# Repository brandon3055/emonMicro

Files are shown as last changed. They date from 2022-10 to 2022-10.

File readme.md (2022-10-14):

# EmonMicro

This is a small self-contained energy monitoring device designed to work with [Open Energy Monitor](https://openenergymonitor.org/)

I recently installed an open energy monitor EmonTx v4 so that I could monitor the power usage of that various circuits in my house. 
but I found myself wanting more information. The tx v4 can for example tell me how much power is being used by the bedroom circuit,
but it can't tell me how much power is going to each room or appliance. This project was started as a solution.

## Disclaimer!
I am not a qualified electrical engineer! I am just a hobbyist who occasionally likes to design and build things.
I am releasing this design so that others may learn from it and possibly improve on it.
If you choose to build this device you do so at your own risk! If it happens to burst into flames, or you
electrocute yourself because you're not qualified to work on mains-powered devices I can not be held responsible.

### The design
The idea behind this project was to build an energy monitor in a form factor similar to a standard power strip.
The board supports up to four separate channels, but I found the most I personally need was three and in most cases i only need one.
Unused channels can simply be left unpopulated.

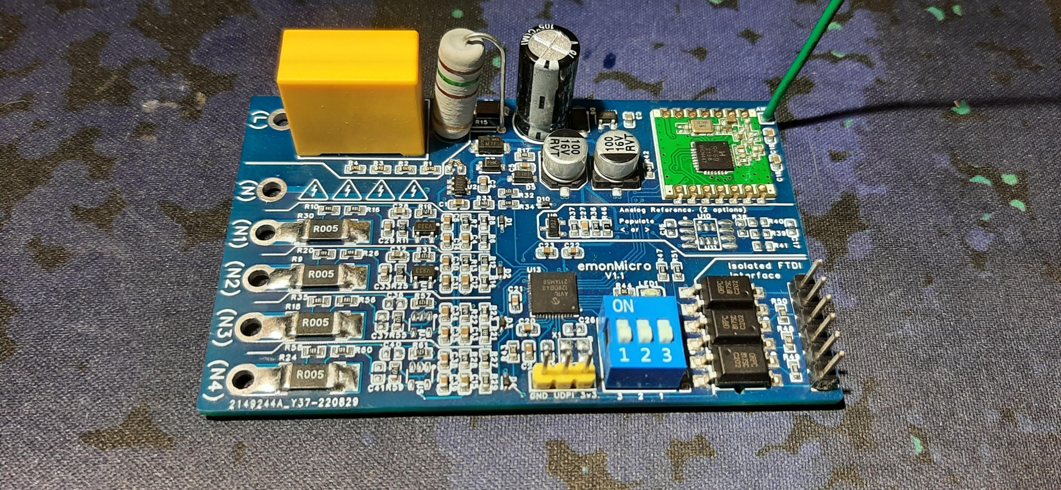
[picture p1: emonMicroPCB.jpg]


For the sockets I used [PW1-0W](https://www.wagneronline.com.au/ac-power-installation/power-240vac/power-lighting/pw1-0w-35241/973869/pd/) panel mount sockets.  
As well as a couple sockets I pulled out of an old UPS.

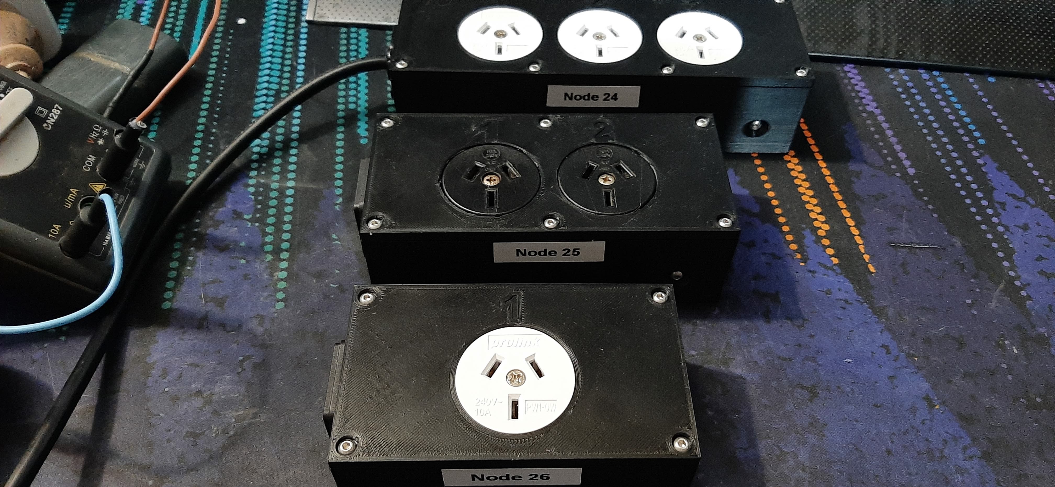
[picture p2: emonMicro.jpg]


For the power input I decided to go with 10A fused IEC ports. I chose these because both the ports and the plugs are rated at 10 amps
and you can get them with built-in fuses, so they seemed like a convenient solution. 
**Turns out this was a mistake...** I later discovered that although the plugs are rated for 10 amps
the vast majority of IEC cables use 0.75mm2 conductors which are only rated for around 7 amps.
So to work around this I have to forgo the fuse and hard-wire suitable cords for use cases that require more than 7 amp capacity.

### Safety and Isolation
Unlike all other OEM devices this design has no isolation between mains and the low voltage electronics.
By eliminating the bulky isolation components and switching to a transformerless power supply I was able to make
the board very compact and reduce component cost. The downside is this means the low voltage electronics are referenced to mains so the entire board
must be fully enclosed in a proper safe enclosure when the device is powered.
This is fine in normal operation but the device still needs to be connected to a computer while powered in order to be calibrated.
The solution I came up with was to add an optically isolated FTDI port that can be safely connected to an FTDI adapter. 

This also means you can't use an external antenna but with a plastic enclosure and internal antenna glued around the perimeter of the box 
seems to provide pretty good range.  

### The power supply and use with 110v power
The only thing stopping this from working with 110v is the value of the capacitor in the transformerless power supply.
I ran some basic simulations to get a rough idea of the value I needed but the monitor does not use a consistent amount of current.
Instead, mostly just sips power until it needs to transmit at which point the TX module pules up to 45ma in short bursts.
Through a bit of trial and error I found that a 680nf input cap with 1000uf buffer cap charged to 9v can more than 
handle the power demands of normal operation. 
on a 110v supply you could theoretically just double value of the input capacitor. Though that would require some testing to be sure.  

### Future plans? 
As of writing this I don't have any immediate plans to continue working on this project.
But its possible I may re visit this project in the future.

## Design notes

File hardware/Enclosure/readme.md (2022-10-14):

# Caution!

If you choose to build these monitors I recommend using a properly rated off the shelf enclosure. 
Failure of the enclosure could result in electrocution. 

If you do choose to print these enclosures I recommend a minimum of 4 perimeters, 5 top/bottom layers and 40% cubic infill.
And please...
#### Do not use PLA!
Seriously. PLA is great for toys and trinkets but with a glass transition temp of 60C you may as well be using candle wax.
I used ABS for my enclosures but PETG *may* also be acceptable.

Just keep in mind if the enclosure fails someone could be electrocuted. So be sure you know what you are doing.

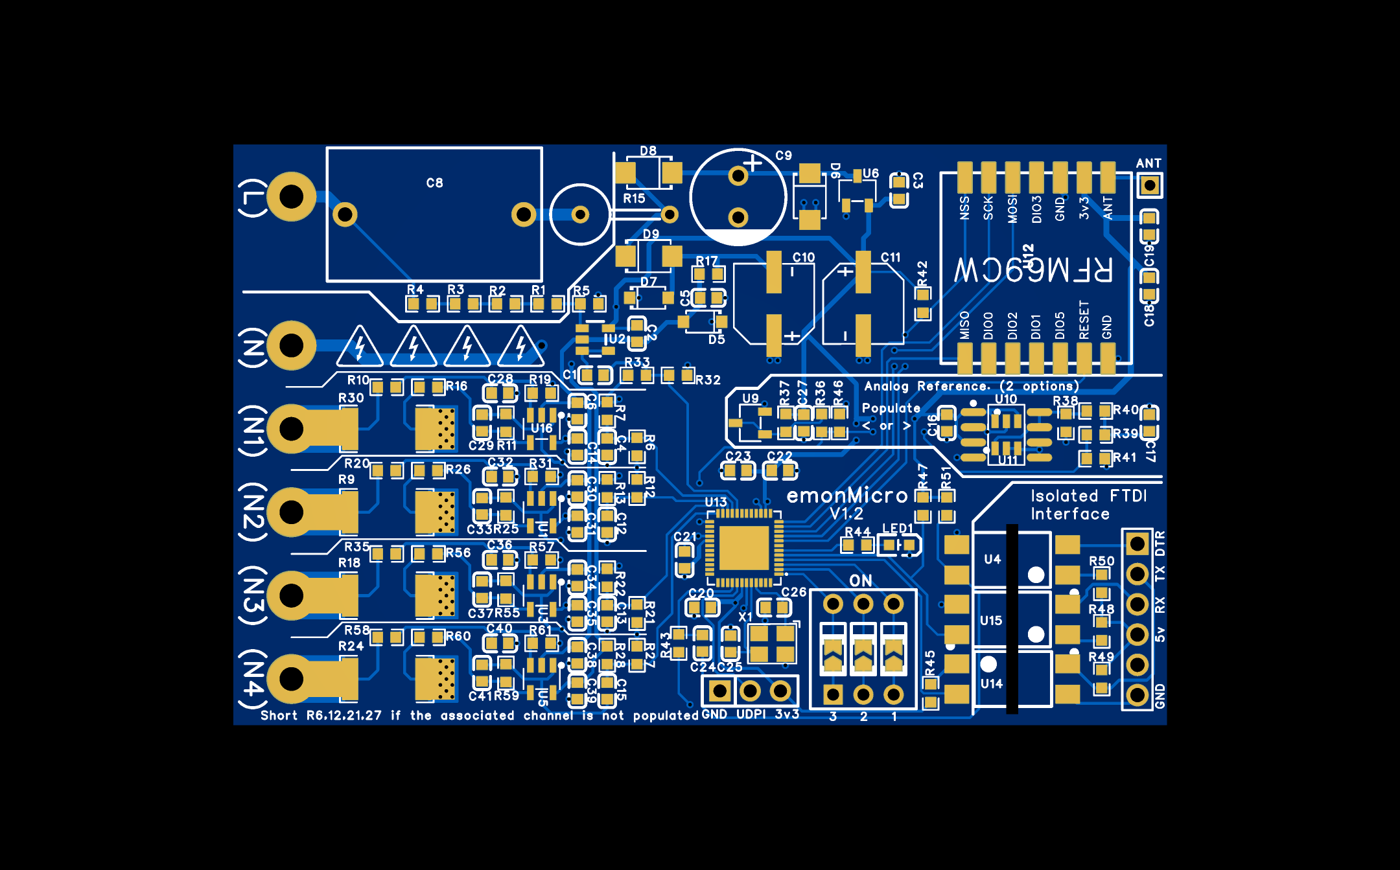
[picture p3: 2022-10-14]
hardware/v1.2/PCB_Top_2022-09-23.png

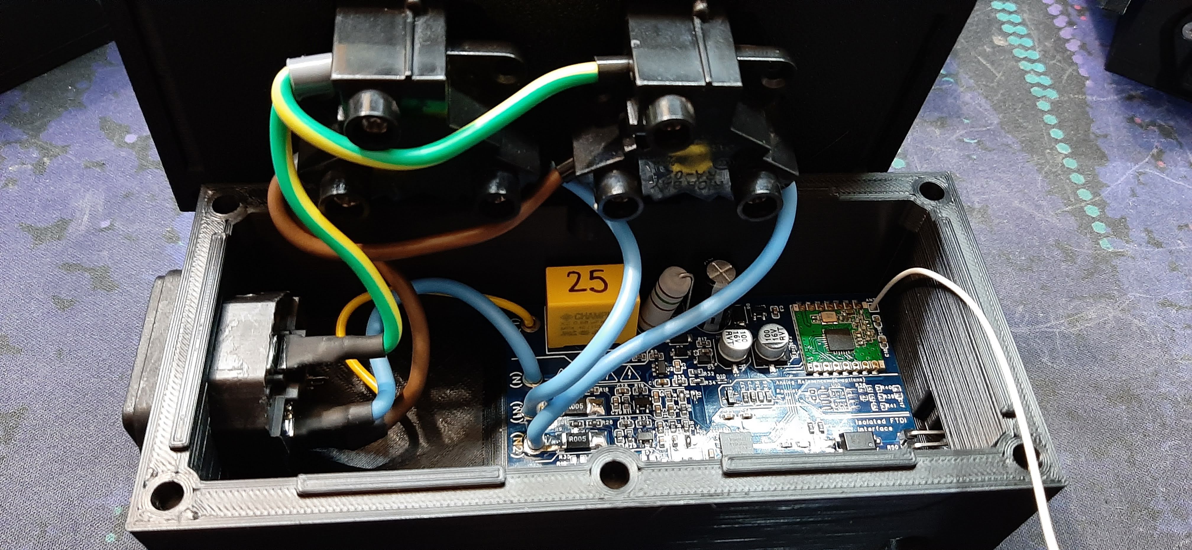
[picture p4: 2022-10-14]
hardware/2-port internal.jpg

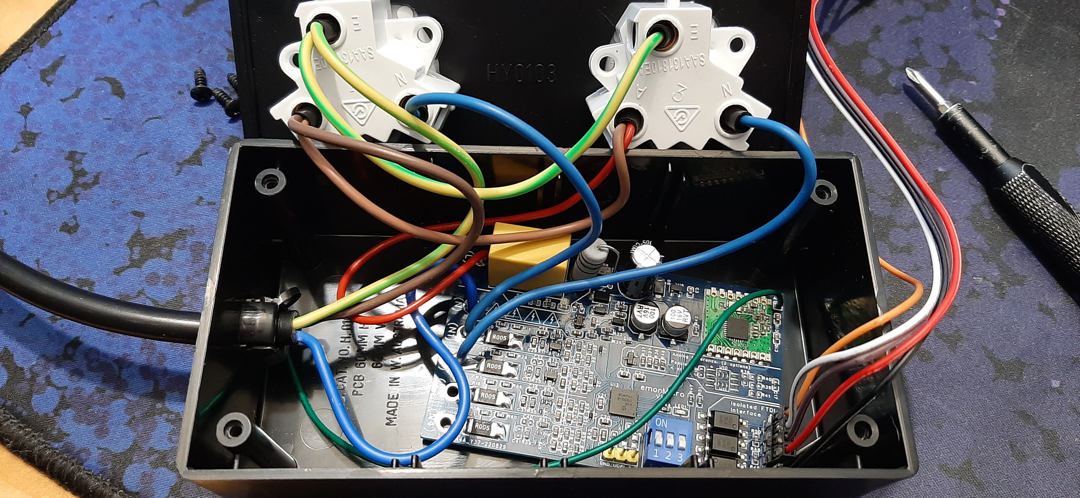
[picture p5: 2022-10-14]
hardware/off-the-shelf enclosure2.jpg

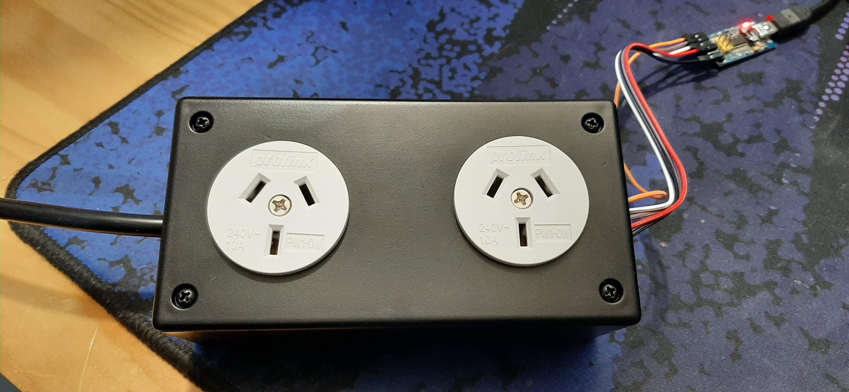
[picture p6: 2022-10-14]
hardware/off-the-shelf enclosure.jpg

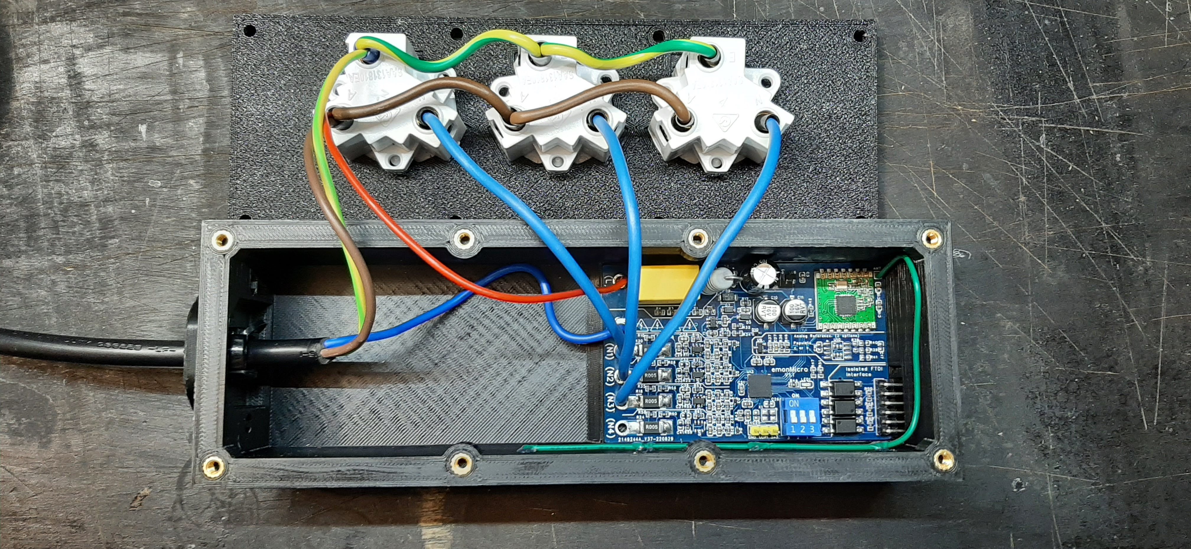
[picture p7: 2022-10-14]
hardware/3-port internal.jpg

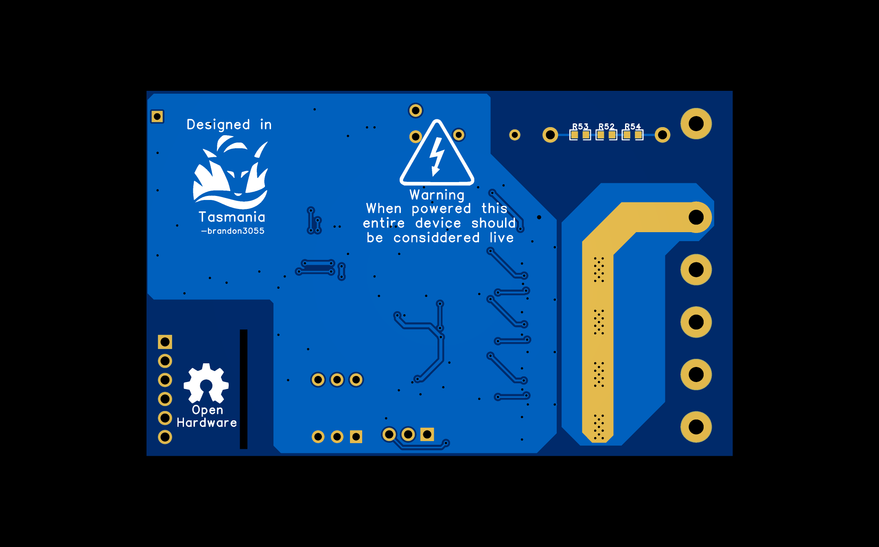
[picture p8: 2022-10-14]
hardware/v1.2/PCB_Bottom_2022-09-23.png

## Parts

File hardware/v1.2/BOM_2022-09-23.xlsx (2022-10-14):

No. | Quantity | Device | Designator | Footprint | Value | Manufacturer Part | Manufacturer | Supplier Part | Supplier
1 | 1 | HDR-M_2.54_1x1P | ANT | HDR-TH_1P-V-M_XKB_X4611WV-01I-C28D40
2 | 6 | CL10A106KP8NNNC | C1,C4,C12,C13,C15,C18 | C0603 | 10uF | CL10A106KP8NNNC | SAMSUNG(三星) | C19702 | LCSC
3 | 16 | TCC0603X7R104K500CT | C2,C3,C5,C6,C14,C19,C20,C21,C22,C24,C30,C31,C34,C35,C38,C39 | C0603 | 100nF | TCC0603X7R104K500CT | CCTC(三环) | C282519 | LCSC
4 | 1 | SMQP684K310XXD5B1515 | C8 | CAP-TH_L18.0-W11.2-P15.00-D1.2 | 680nF | SMQP684K310XXD5B1515 | CHAMPION(全鹏) | C263712 | LCSC
5 | 1 | RK1081CME162RB | C9 | CAP-TH_BD8.0-P3.50-D0.6-FD | 1000uF | RK1081CME162RB | Xunda(讯达) | C398966 | LCSC
6 | 2 | RVT1C101M0605 | C10,C11 | CAP-SMD_BD6.3-L6.6-W6.6-LS7.2-FD | 100uF | RVT1C101M0605 | HONOR(荣誉) | C37308 | LCSC
7 | 3 | CL10A225KO8NNNC | C16,C17,C27 | C0603 | 2.2uF | CL10A225KO8NNNC | SAMSUNG(三星) | C23630 | LCSC
8 | 1 | CL10A105KA8NNNC | C23 | C0603 | 1uF | CL10A105KA8NNNC | SAMSUNG(三星) | C5673 | LCSC
9 | 2 | CC0603JRNPO9BN220 | C25,C26 | C0603 | 22pF | CC0603JRNPO9BN220 | YAGEO(国巨) | C105620 | LCSC
10 | 8 | TCC0603COG102J500CT | C28,C29,C32,C33,C36,C37,C40,C41 | C0603 | 1nF | TCC0603COG102J500CT | CCTC(三环) | C376765 | LCSC
11 | 1 | DDZ9678-7 | D5 | SOD-123_L2.7-W1.6-LS3.7-RD |  | DDZ9678-7 | DIODES(美台) | C150464 | LCSC
12 | 1 | 1SMAF4739A | D6 | SMAF_L3.5-W2.6-LS4.7-RD |  | 1SMAF4739A | 晶导微电子 | C353585 | LCSC
13 | 1 | MM1W5V1 | D7 | SOD-123_L2.7-W1.6-LS3.7-RD |  | MM1W5V1 | 晶导微电子 | C382836 | LCSC
14 | 2 | M7F | D8,D9 | SMAF_L3.5-W2.6-LS4.7-RD |  | M7F | GOODWORK(固得沃克) | C2826370 | LCSC
15 | 1 | HDR-M_2.54_1x6P | FTDI | HDR-TH_6P-P2.54-V-M-1
16 | 3 | Jumper_SolderJumper_2_Bridged | JP1,JP2,JP3 | JUMPER | Solder Jumper
17 | 1 | ORH-B36G | LED1 | LED0603-R-RD |  | ORH-B36G | Orient(奥伦德) | C193191 | LCSC
18 | 4 | TD03G5113BT | R1,R2,R3,R4 | R0603 | 511kΩ | TD03G5113BT | FH(风华) | C667228 | LCSC
19 | 9 | ARG03BTC2001 | R5,R10,R16,R20,R26,R35,R56,R58,R60 | R0603 | 2kΩ | ARG03BTC2001 | Viking(光颉) | C335077 | LCSC
20 | 5 | RT0603BRD0733KL | R6,R12,R21,R27,R32 | R0603 | 33kΩ | RT0603BRD0733KL | YAGEO(国巨) | C705768 | LCSC
21 | 5 | RT0603BRE07180KL | R7,R13,R22,R28,R33 | R0603 | 180kΩ | RT0603BRE07180KL | YAGEO(国巨) | C136958 | LCSC
22 | 4 | FMF25FPJR005-LH | R9,R18,R24,R30 | R2512 | 5mΩ | FMF25FPJR005-LH | PSA(信昌电陶) | C371096 | LCSC
23 | 8 | RT0603BRD0712KL | R11,R19,R25,R31,R55,R57,R59,R61 | R0603 | 12kΩ | RT0603BRD0712KL | YAGEO(国巨) | C326735 | LCSC
24 | 1 | MO3W-150Ω±5%-QT73 | R15 | RES-TH_BD5.0-P7.50-D0.6 | 150Ω | MO3W-150Ω±5%-QT73 | VO(翔胜) | C479252 | LCSC
25 | 1 | HPCR0603F200RK9 | R17 | R0603 | 200Ω | HPCR0603F200RK9 | RESI(开步睿思） | C365116 | LCSC
26 | 1 | RT0603BRE0715KL | R36 | R0603 | 15kΩ | RT0603BRE0715KL | YAGEO(国巨) | C705813 | LCSC
27 | 4 | FRC0603F1001TS | R37,R47,R49,R51 | R0603 | 1k | FRC0603F1001TS | FOJAN(富捷) | C2907002 | LCSC
28 | 3 | 0603WAF1002T5E | R38,R43,R44 | R0603 | 10kΩ | 0603WAF1002T5E | UNI-ROYAL(厚声) | C25804 | LCSC
29 | 2 | ARG03BTC1002 | R39,R41 | R0603 | 10kΩ | ARG03BTC1002 | 光颉(Viking) | C309083 | LCSC
30 | 1 | 0603WAF100JT5E | R40 | R0603 |  | 0603WAF100JT5E | UNI-ROYAL(厚声) | C22859 | LCSC
31 | 1 | 0603WAF1203T5E | R42 | R0603 | 120K | 0603WAF1203T5E | UNI-ROYAL(厚声) | C25808 | LCSC
32 | 3 | 0603WAF5600T5E | R45,R48,R50 | R0603 | 560Ω | 0603WAF5600T5E | UNI-ROYAL(厚声) | C23204 | LCSC
33 | 1 | AR03BTCX5001 | R46 | R0603 | 5kΩ | AR03BTCX5001 | 光颉(Viking) | C2828621 | LCSC
34 | 3 | 0603WAF3653T5E | R52,R53,R54 | R0603 | 365kΩ | 0603WAF3653T5E | UNI-ROYAL(厚声) | C23031 | LCSC
35 | 1 | DS-03BLP | SW1 | SW-TH_6P-L9.2-W9.9-P2.54-LS7.6 |  | DS-03BLP | XKB Connectivity(中国星坤) | C692501 | LCSC
36 | 4 | TLV333AIM5/TR | U1,U3,U5,U16 | SOT-23-5_L3.0-W1.7-P0.95-LS2.8-BL |  | TLV333AIM5/TR | HGSEMI(华冠) | C565346 | LCSC
37 | 1 | LMV321IDBVRG | U2 | SOT-23-5_L2.9-W1.6-P0.95-LS2.8-BR |  | LMV321IDBVRG | HGC(深圳汉芯) | C2977082 | LCSC
38 | 3 | ORPC-817S/C | U4,U14,U15 | SOP-4_L6.4-W4.6-P2.54-LS10.2-BL |  | ORPC-817S/C | Orient(奥伦德) | C191384 | LCSC
39 | 1 | ME6249A33M3G | U6 | SOT-23-3_L2.9-W1.6-P1.90-LS2.8-BR |  | ME6249A33M3G | MICRONE(南京微盟) | C427606 | LCSC
40 | 1 | ADR5040ARTZ-REEL7 | U9 | SOT-23-3_L2.9-W1.6-P1.90-LS2.8-BR |  | ADR5040A | ADI(亚德诺)/LINEAR | C144273 | LCSC
41 | 1 | MCP1501-10E/SN | U10 | SOIC-8_L4.9-W3.9-P1.27-LS6.0-BL |  | MCP1501-10E/SN | MICROCHIP(美国微芯) | C635890 | LCSC
42 | 1 | MCP1501T-10E/CHY | U11 | SOT-23-6_L2.9-W1.6-P0.95-LS2.8-BL |  | MCP1501T-10E/CHY | MICROCHIP(美国微芯) | C99391 | LCSC
43 | 1 | RFM69CW | U12 | RFM69CW
44 | 1 | AVR128DB48-E/6LX | U13 | VQFN-48_L6.0-W6.0-P0.40-BL-EP4.1 |  | AVR128DB48-E/6LX | MICROCHIP(美国微芯) | C1020223 | LCSC
45 | 1 | HDR-M_2.54_1x3P | UDPI | HDR-TH_3P-P2.54-V-M
46 | 1 | X322512MOB4SI | X1 | OSC-SMD_4P-L3.2-W2.5-BL | 12MHz | X322512MOB4SI | YXC扬兴科技 | C70565 | LCSC

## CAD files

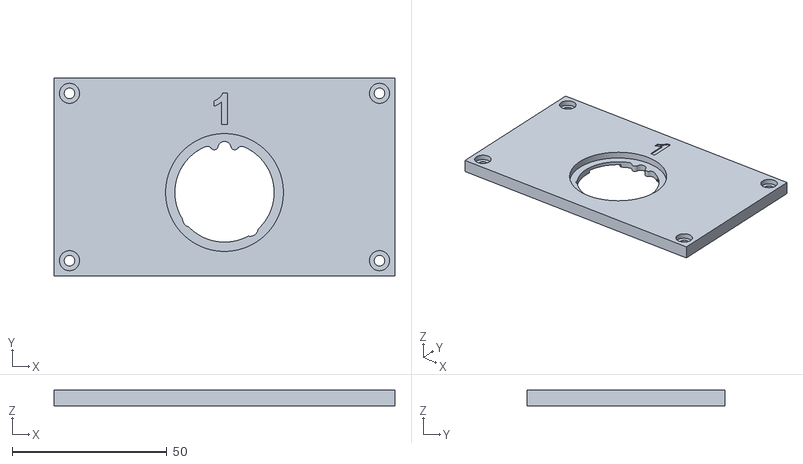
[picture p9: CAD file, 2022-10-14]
hardware/Enclosure/1-port/Enclosure Lid.stl
110.0 x 64.0 x 5.00

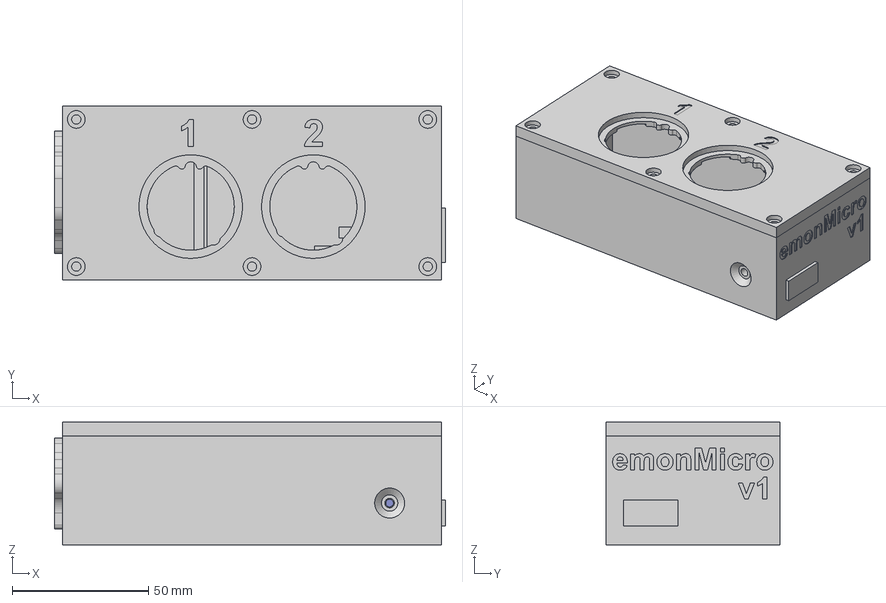
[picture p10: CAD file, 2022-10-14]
hardware/Enclosure/2-port/EmonMicro.step
143.5 x 64.0 x 45.0 mm
Enclosure Base
Enclosure Lid
Opto Shield
Port Cover
Cable Adapter

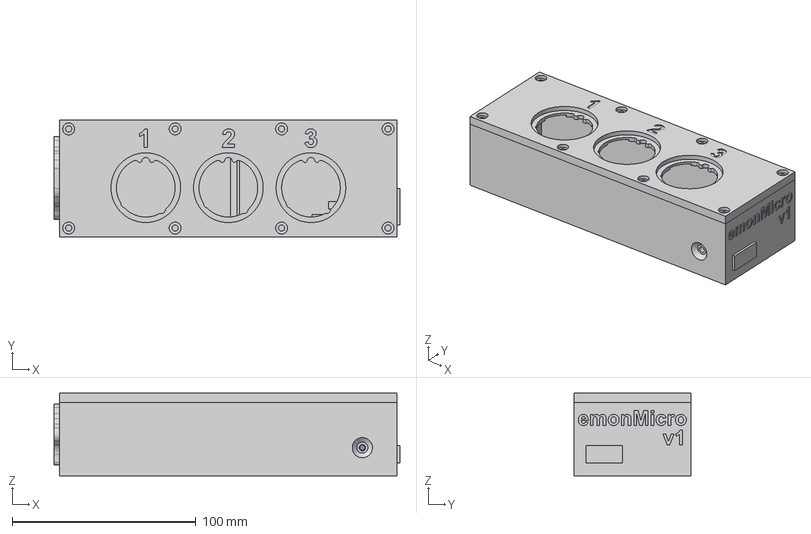
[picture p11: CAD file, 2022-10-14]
hardware/Enclosure/3-port/EmonMicro.step
188.5 x 64.0 x 45.0 mm
Enclosure Base
Enclosure Lid
Opto Shield
Port Cover
Cable Adapter

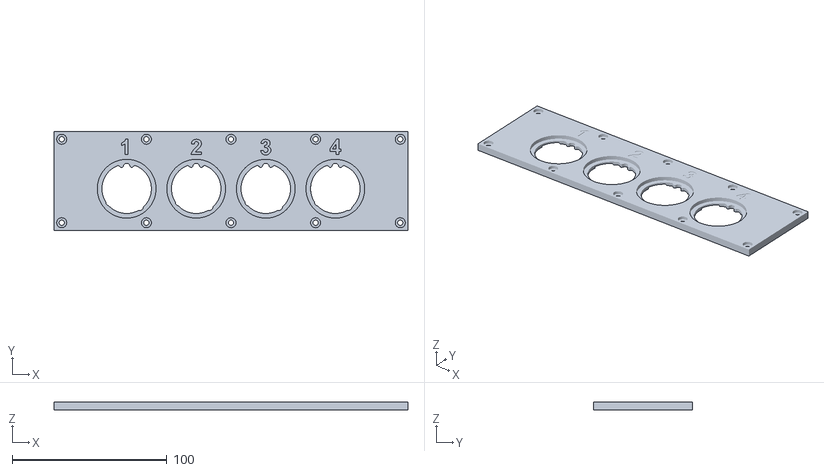
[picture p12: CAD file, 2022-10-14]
hardware/Enclosure/4-port/Enclosure Lid.stl
229.0 x 64.0 x 5.00

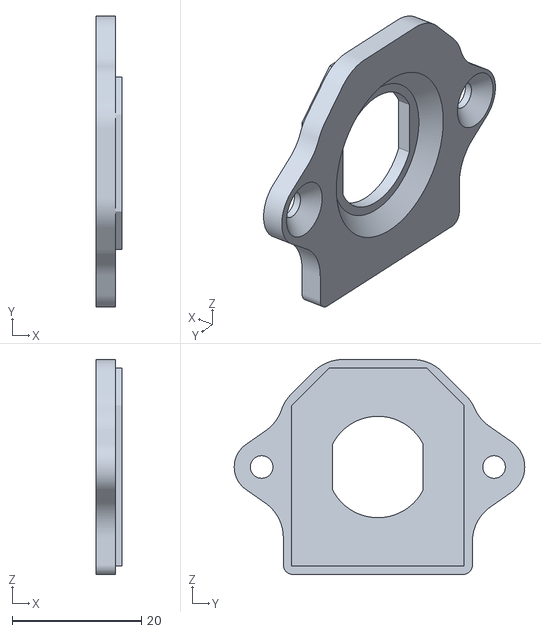
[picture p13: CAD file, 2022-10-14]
hardware/Enclosure/Cable Adapter.stl
4.00 x 45.0 x 33.3

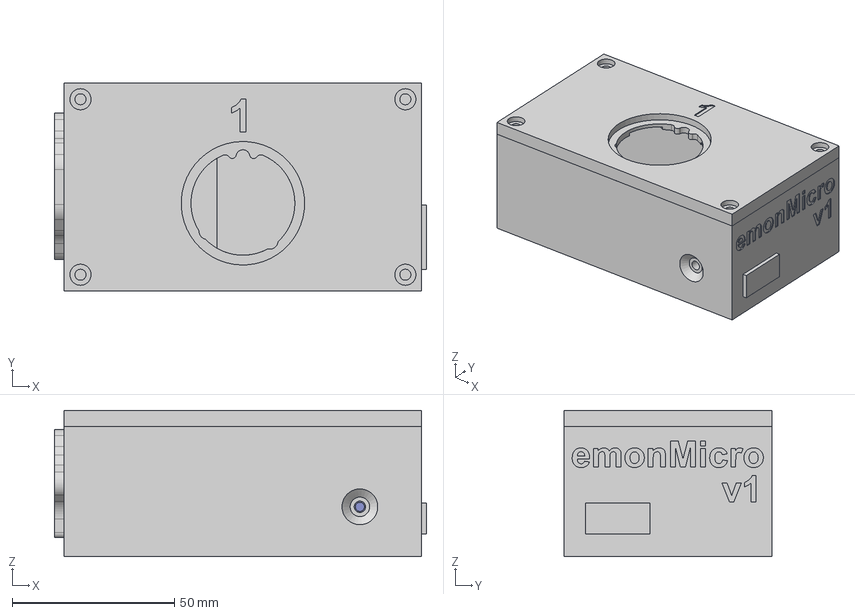
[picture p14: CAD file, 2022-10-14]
hardware/Enclosure/1-port/EmonMicro.step
114.5 x 64.0 x 45.0 mm
Enclosure Base
Enclosure Lid
Opto Shield
Port Cover
Cable Adapter

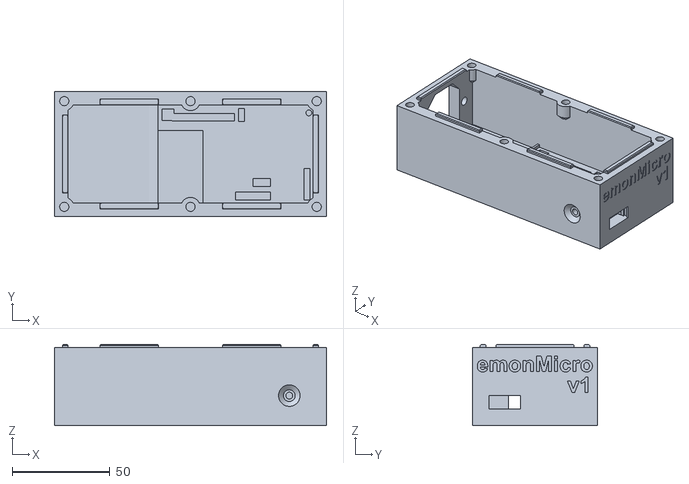
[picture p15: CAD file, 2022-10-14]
hardware/Enclosure/2-port/Enclosure Base.stl
139.0 x 64.0 x 41.5

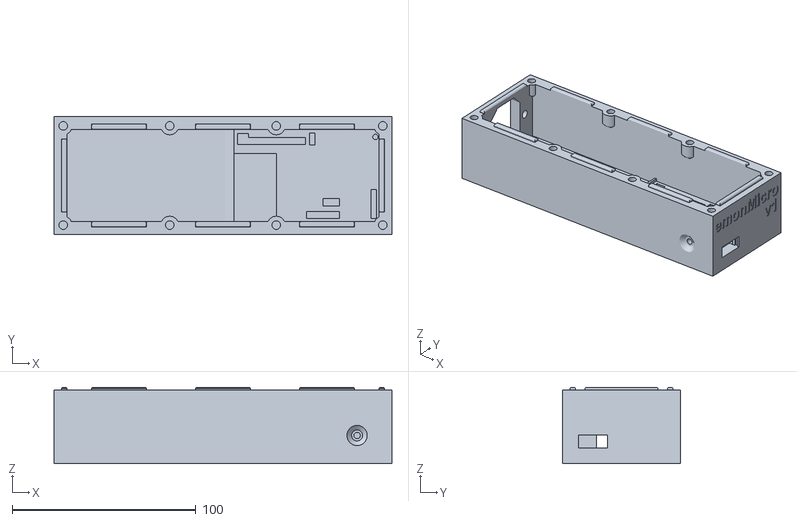
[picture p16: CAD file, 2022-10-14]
hardware/Enclosure/3-port/Enclosure Base.stl
184.0 x 64.0 x 41.5

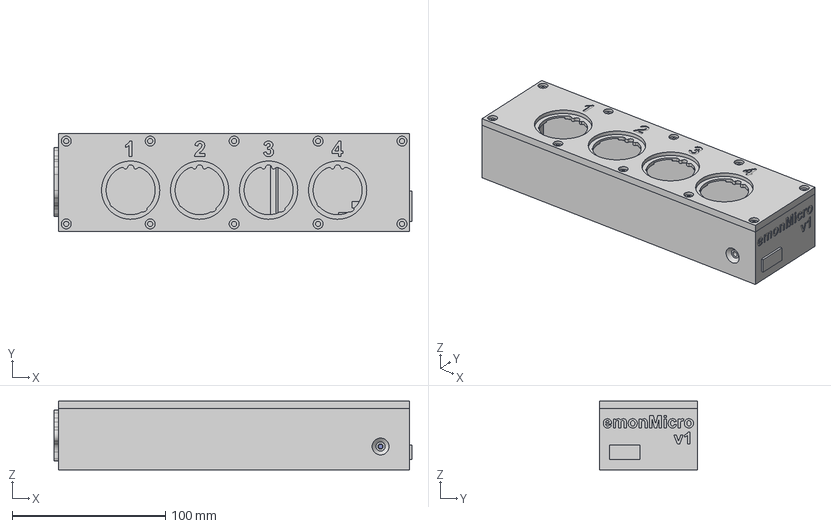
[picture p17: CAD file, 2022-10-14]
hardware/Enclosure/4-port/EmonMicro.step
233.5 x 64.0 x 45.0 mm
Enclosure Base
Enclosure Lid
Opto Shield
Port Cover
Cable Adapter

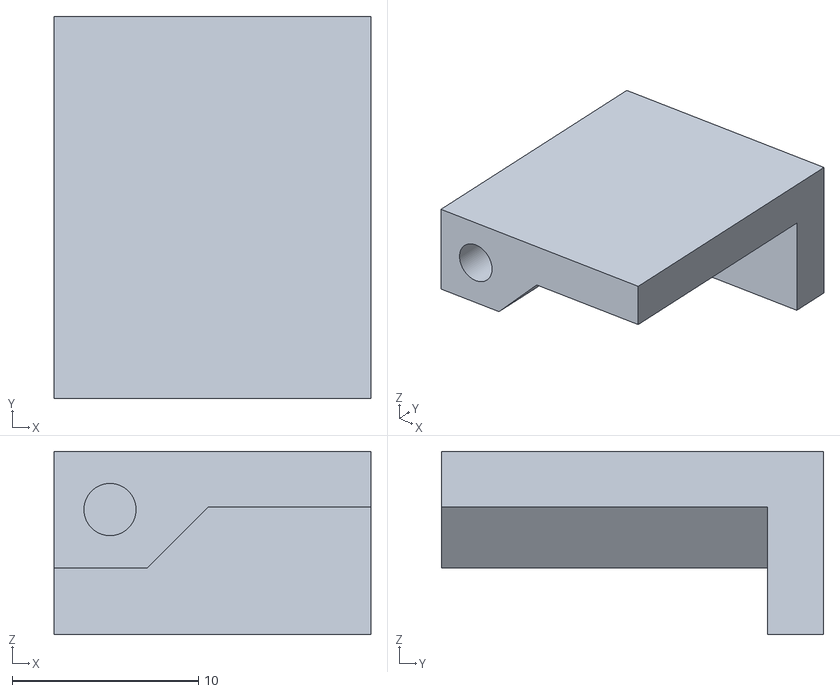
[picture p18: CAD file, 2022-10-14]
hardware/Enclosure/Opto Shield.stl
17.0 x 20.5 x 9.84

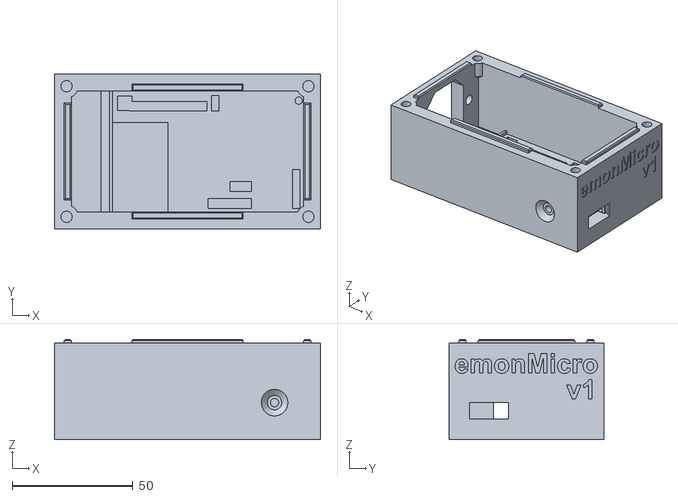
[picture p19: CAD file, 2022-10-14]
hardware/Enclosure/1-port/Enclosure Base.stl
110.0 x 64.0 x 41.5

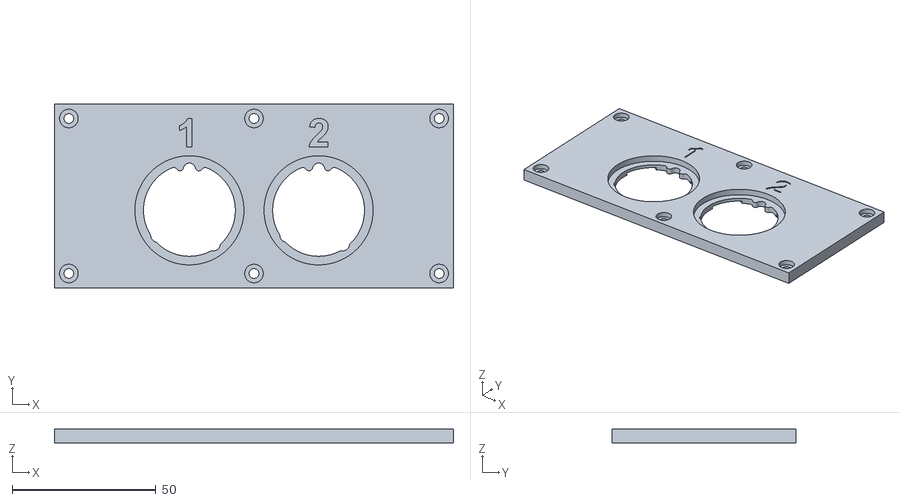
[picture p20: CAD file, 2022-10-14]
hardware/Enclosure/2-port/Enclosure Lid.stl
139.0 x 64.0 x 5.00

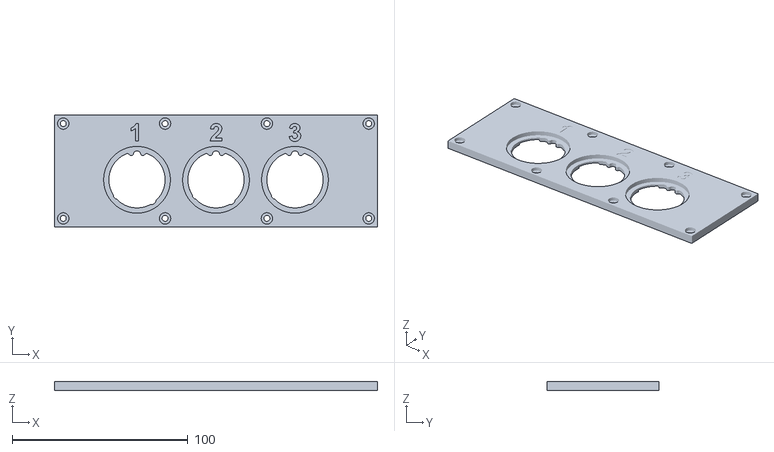
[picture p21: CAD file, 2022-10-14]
hardware/Enclosure/3-port/Enclosure Lid.stl
184.0 x 64.0 x 5.00

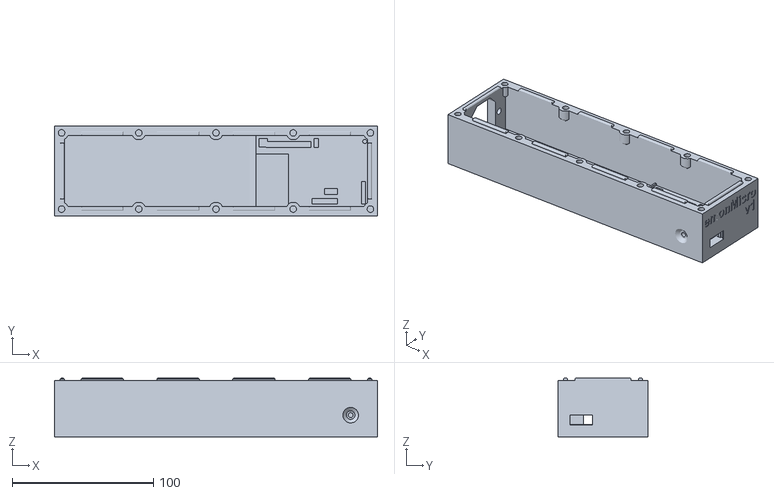
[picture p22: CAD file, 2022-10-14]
hardware/Enclosure/4-port/Enclosure Base.stl
229.0 x 64.0 x 41.5

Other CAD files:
hardware/Enclosure/FTDI Port Cover.stl
hardware/Enclosure/FTDI Port Cover - tight.stl

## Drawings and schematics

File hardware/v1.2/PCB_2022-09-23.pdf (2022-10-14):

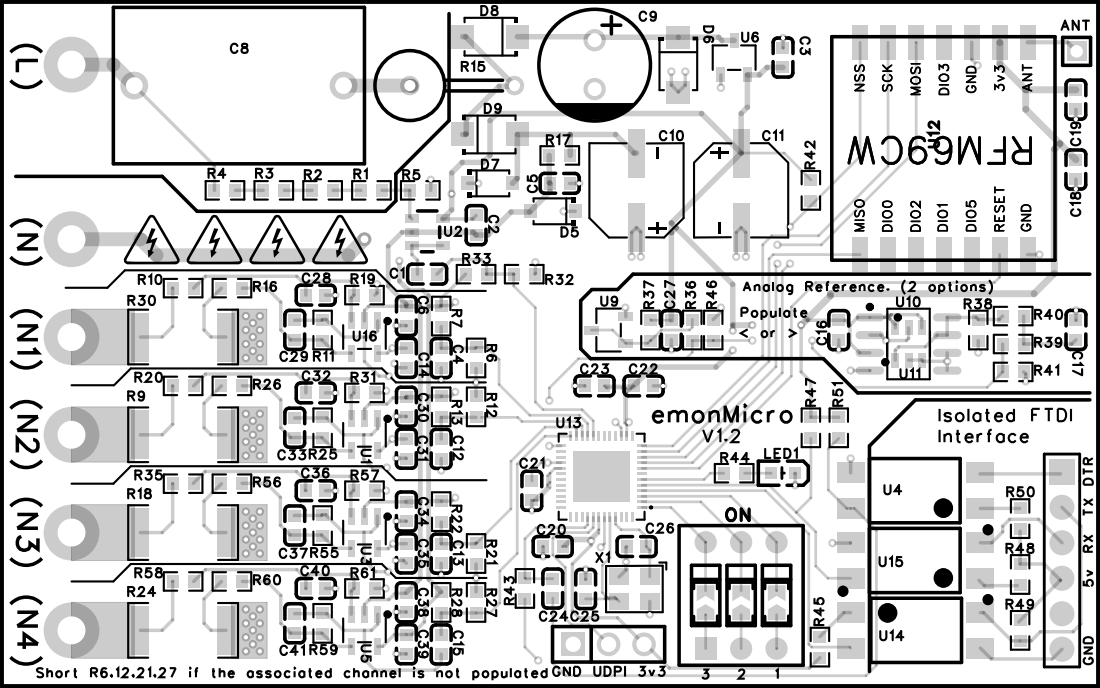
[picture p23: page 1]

Short R6,12,21,27 if the associated channel is not populated

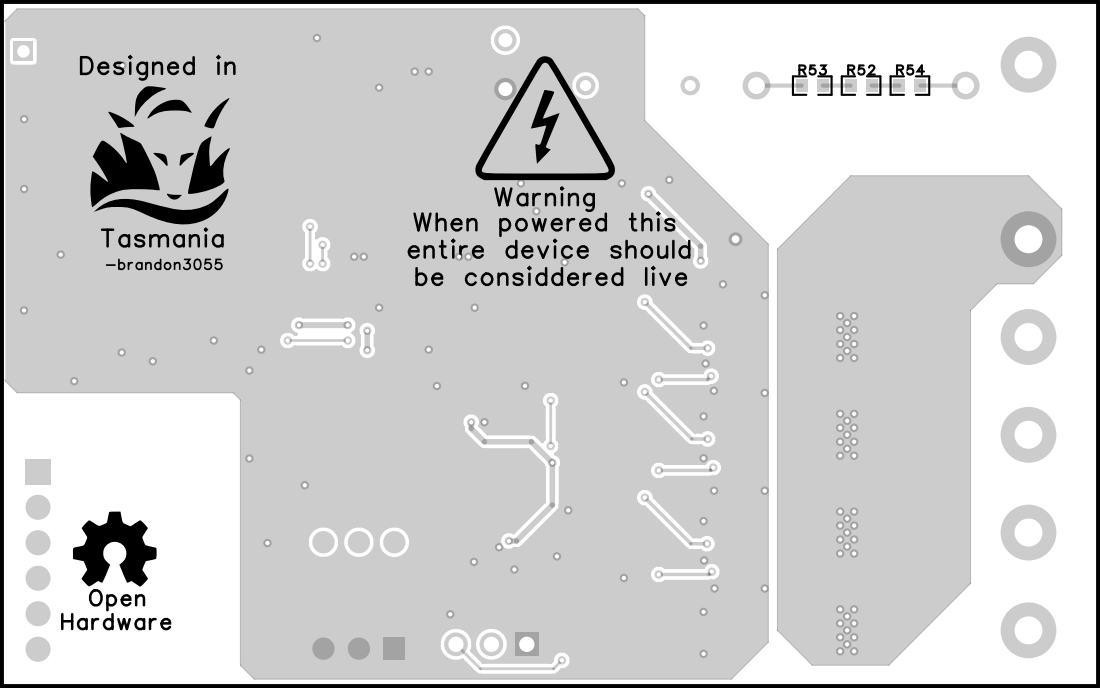
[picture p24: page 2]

Warning When powered this entire device should be considdered live

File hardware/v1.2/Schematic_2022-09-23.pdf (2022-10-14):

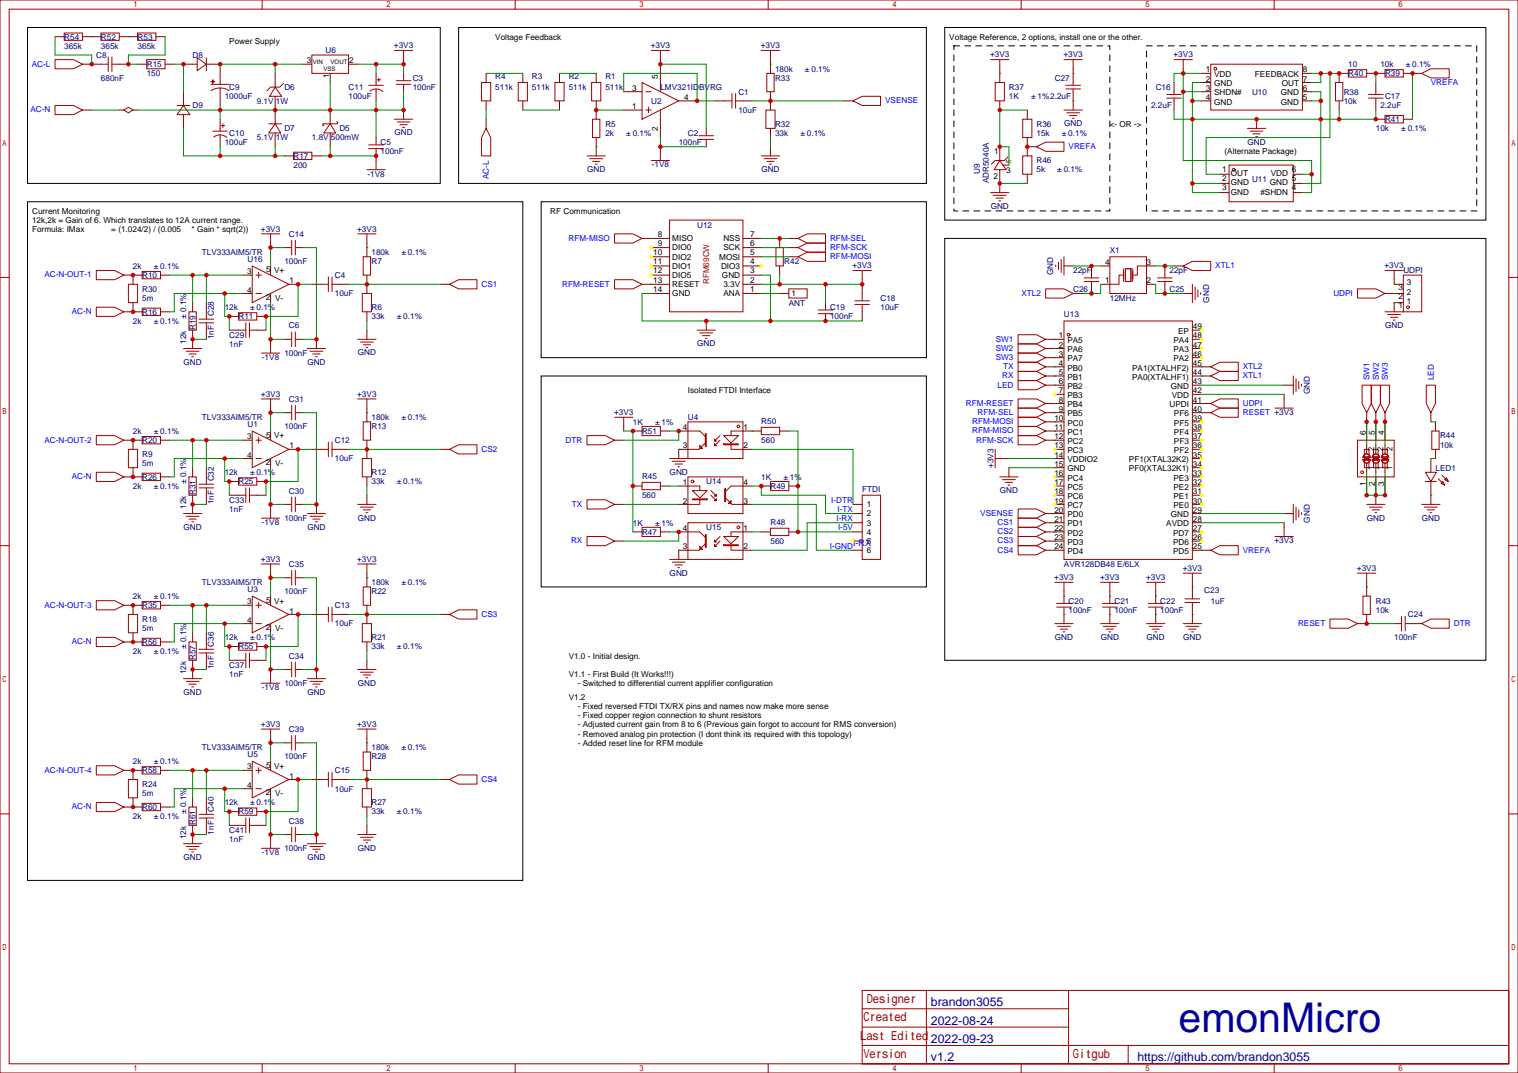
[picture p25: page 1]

Voltage Reference, 2 options, install one or the other.

Current Monitoring
12k,2k = Gain of 6. Which translates to 12A current range.
Formula: IMaxᵣₘₛ = (1.024/2) / (0.005 * Gain * sqrt(2))

V1.0 - Initial design.
V1.1 - First Build (It Works!!!)
- Switched to differential current applifier configuration
- Fixed reversed FTDI TX/RX pins and names now make more sense
- Fixed copper region connection to shunt resistors
- Adjusted current gain from 8 to 6 (Previous gain forgot to account for RMS conversion)
- Removed analog pin protection (I dont think its required with this topology)
- Added reset line for RFM module

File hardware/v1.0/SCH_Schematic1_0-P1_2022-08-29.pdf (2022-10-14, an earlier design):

# Current sensing needs to be converted to differential

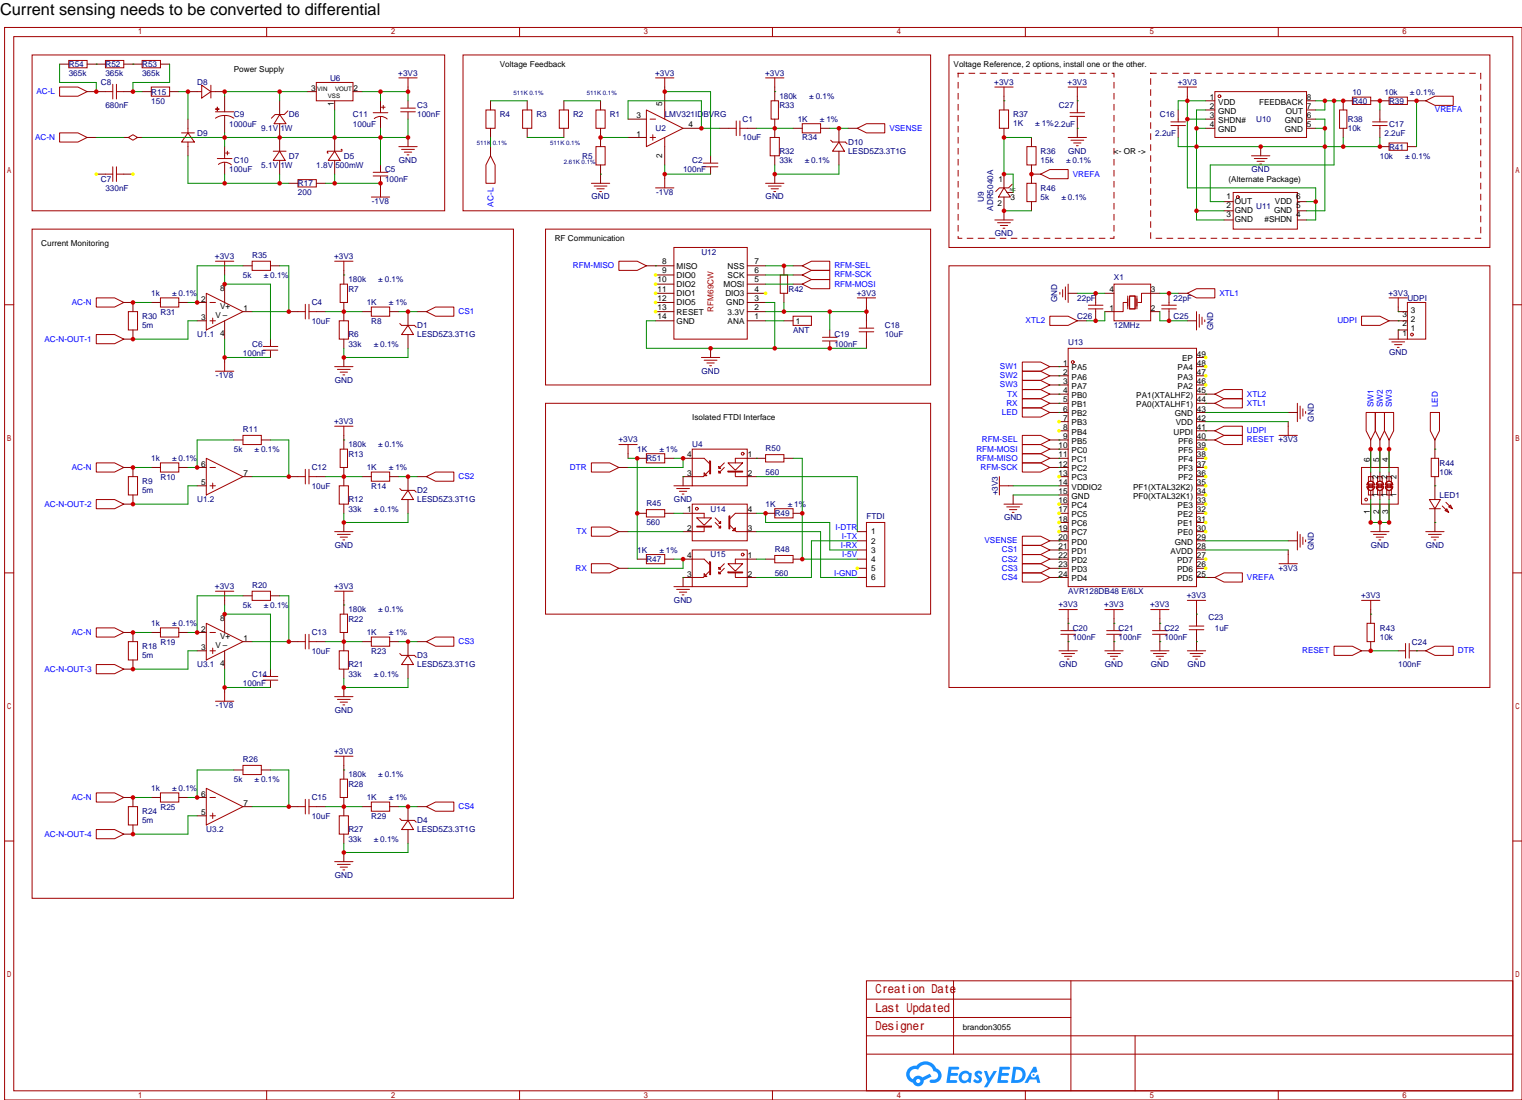
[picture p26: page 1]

Voltage Reference, 2 options, install one or the other.

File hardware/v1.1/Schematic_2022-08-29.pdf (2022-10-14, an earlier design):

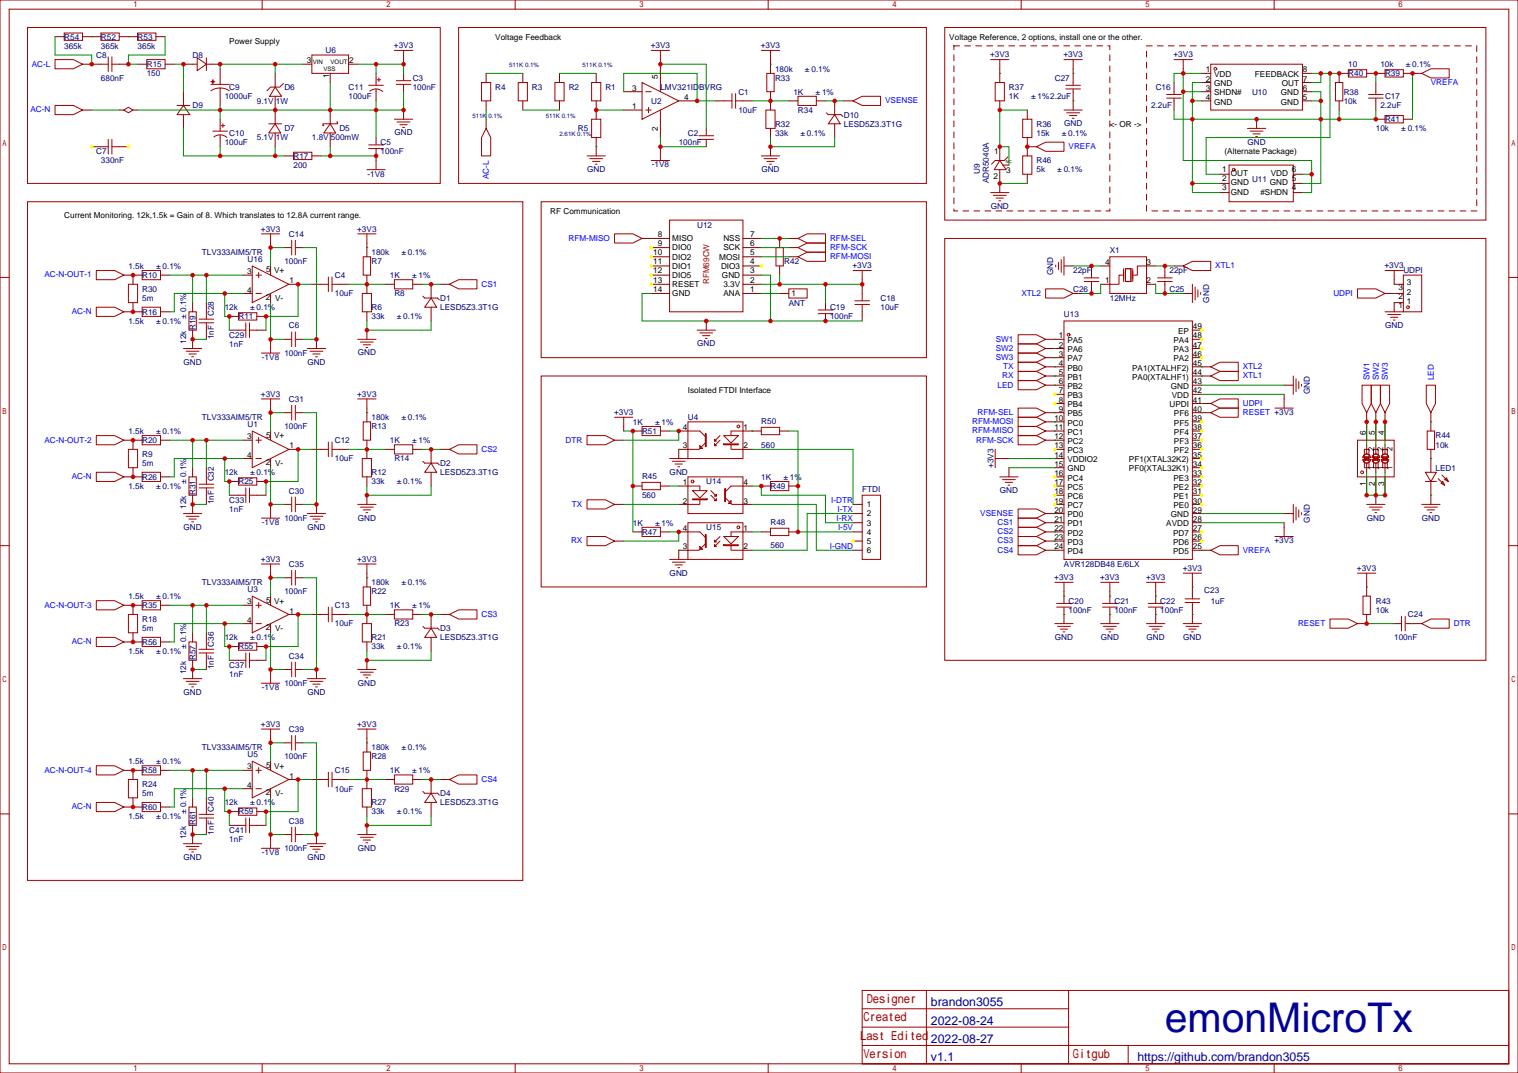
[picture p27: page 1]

Voltage Reference, 2 options, install one or the other.

Current Monitoring. 12k,1.5k = Gain of 8. Which translates to 12.8A current range.

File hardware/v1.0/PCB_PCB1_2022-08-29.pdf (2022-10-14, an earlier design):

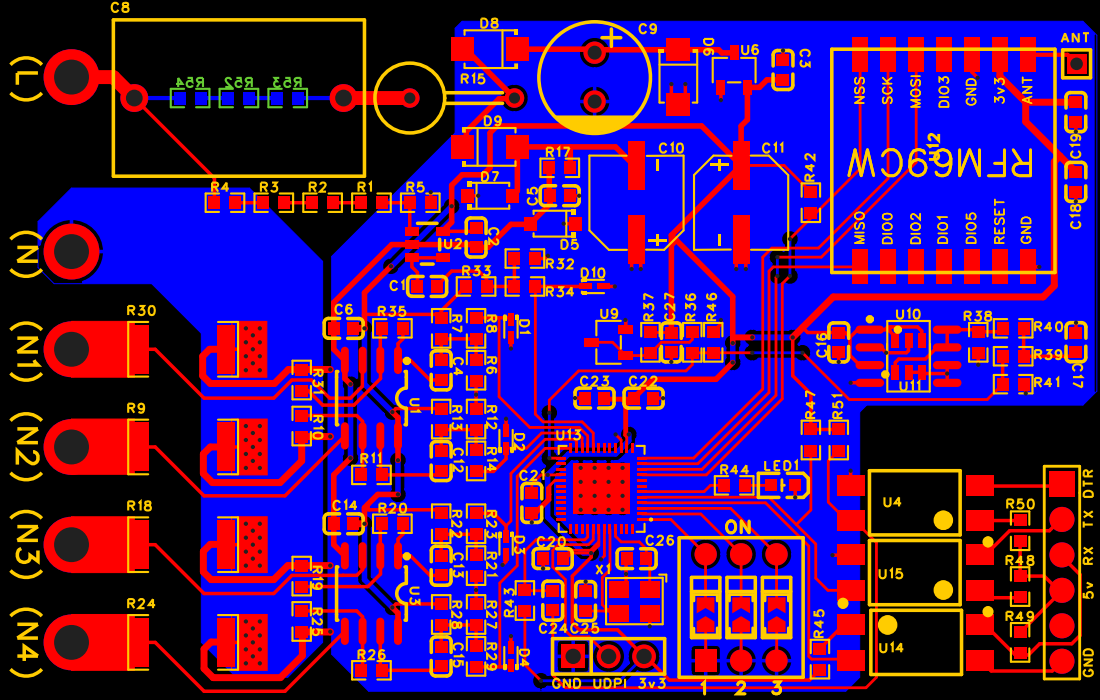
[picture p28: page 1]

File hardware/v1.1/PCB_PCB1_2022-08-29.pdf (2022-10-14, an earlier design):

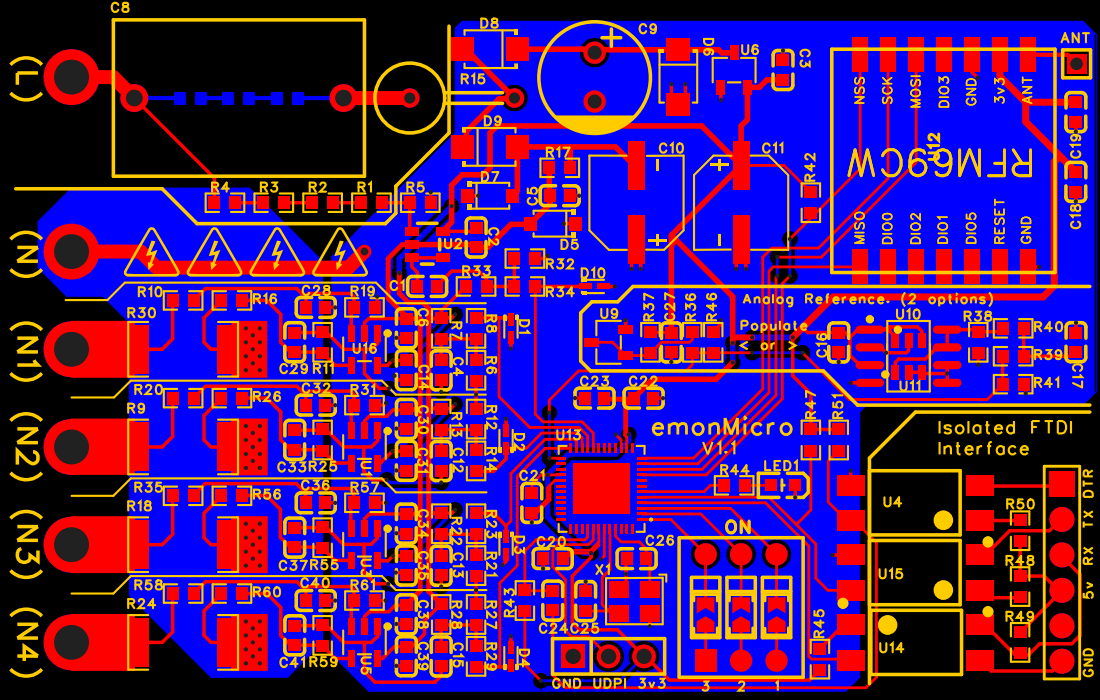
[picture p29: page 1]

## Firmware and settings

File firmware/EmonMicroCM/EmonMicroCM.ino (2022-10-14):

/*
  emonMicro Continuous Sampling
  using EmonLibCM https://github.com/openenergymonitor/EmonLibCM
  Author: brandon3055
  
  -----------------------------------------
  This firmware is based on EmonTxV4CM
  Compatible with openenergymonitor.org project
  Licence: GNU GPL V3

  -----------------------------------------
  Note on uploading.
  Most of the instructions for the EmonTxV4 apply here.
  But due to the use of opto-isolation the communication baud rate is limited to 9600.
  Programming with this baud rate requires a modified version of optiboot that is included in the firmware folder.
  
  This also means uploading directly from the arduino IDE does not work. There is probably a solution to this issue.
  But the simple hack i use is as follows. (This is for linux but it will most likely also apply to windows)
  
  First go to arduino preferences and ensure "Show verbose output" is enabled for upload.
  Next try to uoload the sketch as you would normally. 
  This will fail but the sketch will be compiled and the command used to upload the compiled sketch will be listed in the console output.
  It will look something like this: 
  /home/brandon3055/.arduino15/packages/DxCore/tools/avrdude/6.3.0-arduino17or18/bin/avrdude -C/home/brandon3055/.arduino15/packages/DxCore/hardware/megaavr/1.4.10/avrdude.conf -v -pavr128db48 -carduino -D -P/dev/ttyUSB0 -b115200 -Uflash:w:/tmp/arduino_build_334173/EmonMicroCM.ino.hex:i 
  Now just copy that command, change -b115200 to -b9600 and run the command yourself in a terminal.
  The upload should complete successfully. 
*/

/*
Change Log:
v1.0: First release for EmonMicro.

TODO: Get serial config working

emonhub.conf
See: https://github.com/openenergymonitor/emonhub/blob/emon-pi/configuration.md
copy the following in to emonhub.conf:

Defauld node id is 24, 
The three switches are read as a 3 bit binary number (0 to 7)
This value is addes to the node id.
0,0,0 = 0      0,1,1 = 3      1,1,0 = 6
0,0,1 = 1      1,0,0 = 4      1,1,1 = 7
0,1,0 = 2      1,0,1 = 5

[[24]]
    nodename = emonMicro24
    [[[rx]]]
        names = MSG, Vrms, P1, P2, P3, P4, E1, E2, E3, E4
        datacodes = L,h,h,h,h,h,l,l,l,l
        scales = 1,0.01,1,1,1,1,1,1,1,1
        units = n,V,W,W,W,W,Wh,Wh,Wh,Wh
        whitening = 1

*/

#define Serial Serial3
#include <Arduino.h>

const byte version = 11; 

// Comment/Uncomment as applicable
#define DEBUG                                           // Debug level print out
#define SHOW_CAL                                        // Uncomment to show current for calibration

#define RFM69CW
#define RFMSELPIN PIN_PB5                               // RFM pins
//#define RFPWR 0x99                                    // RFM Power setting - see rfm.ino for more
#define RFPWR 0x9F
#define FACTORYTESTGROUP 1                              // R.F. group for factory test only
#include "emonLibCM.h"

#include <Wire.h>                                       // Required for RFM & temperature measurement
#include <SPI.h>
#include <util/crc16.h>
#include <OneWire.h>

enum rfband {RF12_433MHZ = 1, RF12_868MHZ, RF12_915MHZ }; // frequency band.

byte RF_freq = RF12_433MHZ;                             // Frequency of radio module can be RF12_433MHZ, RF12_868MHZ or RF12_915MHZ. 
byte nodeID = 24;                                       // node ID for this emonMicro.
int networkGroup = 210;                                 // wireless network group, needs to be same as emonBase / emonPi and emonGLCD. OEM default is 210
const int busyThreshold = -97;                          // Signal level below which the radio channel is clear to transmit
const byte busyTimeout = 15;                            // Time in ms to wait for the channel to become clear, before transmitting anyway
int rf_whitening = 2;                                   // RF & data whitening - 0 = no RF, 1 = RF on, no whitening, default = 2: RF is ON with whitening.

typedef struct {
    unsigned long Msg;
    int Vrms,P1,P2,P3,P4; 
    long E1,E2,E3,E4;
} PayloadTX;
PayloadTX emontx;                                       // create an instance


//----------------------------emonMicro V1 Settings - Shared with config.ino------------------------
#define PHASECAL 1.5

//5mR shunt, 6 x gain
float i1Cal = 33.333333;                 // 1 / (0.005 * 6) = 33.3333
float i1Lead = PHASECAL;
float i2Cal = 33.333333;         
float i2Lead = PHASECAL;
float i3Cal = 33.333333;         
float i3Lead = PHASECAL; 
float i4Cal = 33.333333;         
float i4Lead = PHASECAL;

float vCal  = 1023;          // (4 x 511) = 2044, (2044 + 2) / 2 = 1023
const float vCal_USA = 1023; // Will be the same

bool  USA=false;
float assumedVrms2 = 240.0;  // voltage to use for calculating assumed apparent power if a.c input is absent.
float period = 9.94;        // datalogging period

//----------------------------emonMicro V1 hard-wired connections-----------------------------------
const byte LEDpin      = PIN_PB2;  // emonMicro V1 LED
const byte DIP_switch1 = PIN_PA5;  
const byte DIP_switch2 = PIN_PA6;  
const byte DIP_switch3 = PIN_PA7;  
const byte RFM_reset   = PIN_PB4; 

//---------------------------------CS availability status----------------------------------------

byte CS_count = 0;
bool CS1, CS2, CS3, CS4; // Record if shunt present during startup

//----------------------------------------Setup--------------------------------------------------


void setup() {
  pinMode(LEDpin, OUTPUT);
  digitalWrite(LEDpin,HIGH);
  
  pinMode(DIP_switch1, INPUT_PULLUP);
  pinMode(DIP_switch2, INPUT_PULLUP);
  pinMode(DIP_switch3, INPUT_PULLUP);

  int channelOffset = (!digitalRead(DIP_switch1) << 2) | (!digitalRead(DIP_switch2) << 1) | !digitalRead(DIP_switch3);
  nodeID += channelOffset;
  //Add a slight additional offset based on channel offset.
  //The down side here is the transmitters will occasionally sync up and step on each other.
  //But it ensures senders will never be able to end up perminently in sync.
//  period -= (channelOffset * 0.02); //(Moved to after config load)

  // Enabled Channel Detection---------------------------------------------------------------------------------

//  pinMode(PIN_PD1, INPUT_PULLUP);
//  pinMode(PIN_PD2, INPUT_PULLUP);
//  pinMode(PIN_PD3, INPUT_PULLUP);
//  pinMode(PIN_PD4, INPUT_PULLUP);
//  CS1 = !digitalRead(PIN_PD1);
//  CS2 = !digitalRead(PIN_PD2);
//  CS3 = !digitalRead(PIN_PD3);
//  CS4 = !digitalRead(PIN_PD4);
//  pinMode(PIN_PD1, INPUT);
//  pinMode(PIN_PD2, INPUT);
//  pinMode(PIN_PD3, INPUT);
//  pinMode(PIN_PD4, INPUT);
//
//  CS_count = CS1 + CS2 + CS3 + CS4;
  
  // Serial---------------------------------------------------------------------------------
  Serial.begin(9600);
  
  #ifdef DEBUG
    Serial.print(F("emonMicro V1 EmonLibCM Continuous Monitoring V")); Serial.println(version*0.1);
    Serial.println(F("OpenEnergyMonitor.org"));
    Serial.print(F("NodeID Offset: ")); Serial.println(channelOffset);
//    Serial.print(F("Detected Channels: ")); Serial.println(CS_count);
  #else
    Serial.println(F("describe:EmonMicroCM"));
  #endif

  load_config(true);
  period -= (channelOffset * 0.02);  

  // Reset RFM module ---------------------------------------------------------------------------------
  
  // The 3.3v rail rises a little slow on powerup. This does not seem to cause any issues for the AVR
  // but it does occasionally cause the RFM module to lock up on the first rfm_send call.
  // Resetting the RFM module after powerup is a simple way to resolve this issue. 
  pinMode(RFM_reset, OUTPUT);
  digitalWrite(RFM_reset, HIGH);
  delay(50);
  digitalWrite(RFM_reset, LOW);
  pinMode(RFM_reset, INPUT);
  delay(50);

  //On my v1.1 boards i added a bodge wire from one of the unused crystal pins to reset the RFM module
  //This is not needed with the latest board revision.
//  pinMode(PIN_PA0, OUTPUT);
//  digitalWrite(PIN_PA0, HIGH);
//  delay(50);
//  digitalWrite(PIN_PA0, LOW);
//  delay(50);
  
  
  pinMode(RFMSELPIN, INPUT_PULLUP);
    if (digitalRead(RFMSELPIN)==LOW) {
    rf_whitening = 0;
    Serial.println(F("RFM Select pin LOW, ESP32 Taking control of RFM69"));
  } else {
    // Serial.println(F("RFM Select pin HIGH"));
  }
  
  if (rf_whitening)
  {
    #ifdef DEBUG
      Serial.print(F("RFM69CW only"));
      Serial.print(F(" Node: ")); Serial.print(nodeID);
      Serial.print(" Freq: ");
      if (RF_freq == RF12_433MHZ) Serial.print(F("433MHz"));
      if (RF_freq == RF12_868MHZ) Serial.print(F("868MHz"));
      if (RF_freq == RF12_915MHZ) Serial.print(F("915MHz"));
      Serial.print(F(" Group: ")); Serial.println(networkGroup);
      Serial.println(" ");
    #endif
  }

  digitalWrite(LEDpin,LOW);

  readConfigInput();

  if (rf_whitening)
  {
    #ifdef DEBUG
      Serial.println(F("Pre Init RF"));
    #endif
    rfm_init(RF_freq);     
    #ifdef DEBUG
      Serial.println(F("RF Init Finished"));
    #endif
    // initialize RFM
    for (int i=10; i>=0; i--)                                             // Send RF test sequence (for factory testing)
    {
      emontx.P1=i;
      PayloadTX tmp = emontx;
      if (rf_whitening == 2)
      {
          byte WHITENING = 0x55;
          for (byte i = 0, *p = (byte *)&tmp; i < sizeof tmp; i++, p++)
              *p ^= (byte)WHITENING;
      }
//      #ifdef DEBUG
//        Serial.println(F("rfs"));
//      #endif
      rfm_send((byte *)&tmp, sizeof(tmp), FACTORYTESTGROUP, nodeID, busyThreshold, busyTimeout);
      delay(100);
    }
    emontx.P1=0;
  }

//  Serial.println(F("Ini send complete"));

  // ---------------------------------------------------------------------------------------
  

  // ----------------------------------------------------------------------------
  // EmonLibCM config
  // ----------------------------------------------------------------------------
  // 12 bit ADC = 4096 divisions
  // Time in microseconds for one ADC conversion: 40 us 
  EmonLibCM_setADC(12,29.5);

  // Using AVR-DB 1.024V internal voltage reference
  EmonLibCM_ADCCal(1.024);
  
  EmonLibCM_SetADC_VChannel(0, vCal);                      // ADC Input channel, voltage calibration
  if (USA) EmonLibCM_SetADC_VChannel(0, vCal_USA);
  EmonLibCM_SetADC_IChannel(1, i1Cal, i1Lead);             // ADC Input channel, current calibration, phase calibration
  EmonLibCM_SetADC_IChannel(2, i2Cal, i2Lead);
  EmonLibCM_SetADC_IChannel(3, i3Cal, i3Lead);
  EmonLibCM_SetADC_IChannel(4, i4Cal, i4Lead);

  // mains frequency 50Hz
  if (USA) EmonLibCM_cycles_per_second(60);                // mains frequency 60Hz
  EmonLibCM_datalog_period(period);                        // period of readings in seconds - normal value for emoncms.org  
  
  EmonLibCM_Init();                                        // Start continuous monitoring.
  emontx.Msg = 0;

  #ifdef DEBUG
    Serial.println(F("Setup Complete"));
  #endif
}

void loop() {
  static double E1 = 0.0, E2 = 0.0, E3 = 0.0, E4 = 0.0;    // Sketch's own value to use when a.c. fails.
  getCalibration();
  
  if (EmonLibCM_Ready())   
  {
    #ifdef DEBUG
    if (emontx.Msg==0) {
      Serial.println(EmonLibCM_acPresent()?F("AC present "):F("AC missing "));
      delay(5);
    }
    #endif

    emontx.Msg++;

    // Other options calculated by EmonLibCM
    // RMS Current:    EmonLibCM_getIrms(ch)
    // Apparent Power: EmonLibCM_getApparentPower(ch)
    // Power Factor:   EmonLibCM_getPF(ch)

    if (EmonLibCM_acPresent())
    {
      emontx.P1 = EmonLibCM_getRealPower(0); 
      emontx.E1 = EmonLibCM_getWattHour(0); 
      E1        = EmonLibCM_getWattHour(0);

      emontx.P2 = EmonLibCM_getRealPower(1); 
      emontx.E2 = EmonLibCM_getWattHour(1); 
      E2        = EmonLibCM_getWattHour(1);
      
      emontx.P3 = EmonLibCM_getRealPower(2); 
      emontx.E3 = EmonLibCM_getWattHour(2); 
      E3        = EmonLibCM_getWattHour(2);
    
      emontx.P4 = EmonLibCM_getRealPower(3); 
      emontx.E4 = EmonLibCM_getWattHour(3); 
      E4        = EmonLibCM_getWattHour(3);
    }
    else
    {
      emontx.P1 = assumedVrms2 * EmonLibCM_getIrms(0);       // Alternative calculations for estimated power & energy  
      emontx.P2 = assumedVrms2 * EmonLibCM_getIrms(1);       //   when no a.c. voltage is available
      emontx.P3 = assumedVrms2 * EmonLibCM_getIrms(2);       // Alternative calculations for estimated power & energy  
      emontx.P4 = assumedVrms2 * EmonLibCM_getIrms(3);       //   when no a.c. voltage is available
      
      E1       += assumedVrms2 * EmonLibCM_getIrms(0) * EmonLibCM_getDatalog_period()/3600.0;
      emontx.E1 = E1 + 0.5;                                        // rounded value
      E2       += assumedVrms2 * EmonLibCM_getIrms(1) * EmonLibCM_getDatalog_period()/3600.0;
      emontx.E2 = E2 + 0.5;                                        // rounded value
      E3       += assumedVrms2 * EmonLibCM_getIrms(2) * EmonLibCM_getDatalog_period()/3600.0;
      emontx.E3 = E3 + 0.5;                                        // rounded value
      E4       += assumedVrms2 * EmonLibCM_getIrms(3) * EmonLibCM_getDatalog_period()/3600.0;
      emontx.E4 = E4 + 0.5;                                        // rounded value
    }
    emontx.Vrms = EmonLibCM_getVrms() * 100;
  
    if (rf_whitening)
    {
//      Serial.println(F("About to Send"));
      PayloadTX tmp = emontx;
      if (rf_whitening == 2)
      {
          byte WHITENING = 0x55;
          for (byte i = 0, *p = (byte *)&tmp; i < sizeof tmp; i++, p++)
              *p ^= (byte)WHITENING;
      }
      rfm_send((byte *)&tmp, sizeof(tmp), networkGroup, nodeID, busyThreshold, busyTimeout);     //send data
      delay(50);
    }

    // ---------------------------------------------------------------------
    // Key:Value format, used by EmonESP & emonhub EmonHubTx3eInterfacer
    // ---------------------------------------------------------------------
    Serial.print(F("MSG:")); Serial.print(emontx.Msg);
    Serial.print(F(",Vrms:")); Serial.print(emontx.Vrms*0.01);
    
    Serial.print(F(",P1:")); Serial.print(emontx.P1);
    Serial.print(F(",P2:")); Serial.print(emontx.P2);
    Serial.print(F(",P3:")); Serial.print(emontx.P3);
    Serial.print(F(",P4:")); Serial.print(emontx.P4);
  
    Serial.print(F(",E1:")); Serial.print(emontx.E1);
    Serial.print(F(",E2:")); Serial.print(emontx.E2);
    Serial.print(F(",E3:")); Serial.print(emontx.E3);
    Serial.print(F(",E4:")); Serial.print(emontx.E4);
    
    delay(20);

    digitalWrite(LEDpin,HIGH); delay(50);digitalWrite(LEDpin,LOW);

//// ###################### Testing
//        Serial.println();
//      Serial.print(F("I1:")); Serial.print(EmonLibCM_getIrms(0),3);
//      Serial.print(F(",I2:")); Serial.print(EmonLibCM_getIrms(1),3);
//      Serial.print(F(",I3:")); Serial.print(EmonLibCM_getIrms(2),3);
//      Serial.print(F(",I4:")); Serial.print(EmonLibCM_getIrms(3),3);
//
//  Serial.println();
//      Serial.print(F("A1:")); Serial.print(analogRead(PIN_PD3));
//      Serial.print(F(",A2:")); Serial.print(analogRead(PIN_PD4));
//      Serial.print(F(",A3:")); Serial.print(analogRead(PIN_PD5));
//      Serial.print(F(",A4:")); Serial.print(analogRead(PIN_PD6));
//// ######################


    #ifdef SHOW_CAL
      // to show current & power factor for calibration:
      Serial.println();
      Serial.print(F(",I1:")); Serial.print(EmonLibCM_getIrms(0),3);
      Serial.print(F(",I2:")); Serial.print(EmonLibCM_getIrms(1),3);
      Serial.print(F(",I3:")); Serial.print(EmonLibCM_getIrms(2),3);
      Serial.print(F(",I4:")); Serial.print(EmonLibCM_getIrms(3),3);

      Serial.print(F(",pf1:")); Serial.print(EmonLibCM_getPF(0),4);
      Serial.print(F(",pf2:")); Serial.print(EmonLibCM_getPF(1),4);
      Serial.print(F(",pf3:")); Serial.print(EmonLibCM_getPF(2),4);
      Serial.print(F(",pf4:")); Serial.print(EmonLibCM_getPF(3),4);

    #endif
    Serial.println();
    
    // End of print out ----------------------------------------------------
  }
  //wdt_reset();
  delay(20);
}

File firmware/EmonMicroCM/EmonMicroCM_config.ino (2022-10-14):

/*
 
Configuration file for EmonMicro.ino - V2.3 

EEPROM layout

Byte
0     NodeID
1     RF Freq
2     Network Group
3-6   vCal

7-10  i1Cal
11-14 i1Lead
15-18 i2Cal
19-22 i2Lead
23-26 i3Cal
27-30 i3Lead
31-34 i4Cal
35-38 i4Lead

51-54  Datalogging period
55     Pulses enabled
56-57  Pulse min period
58     Temperatures enabled
59-106 Temperature Addresses (6×8)
107    Data whitening
108-111 assumedVrms

*/
#define Serial Serial3
#include <Arduino.h>
#include <avr/pgmspace.h>
#include <EEPROM.h>

 // Available Serial Commands
const PROGMEM char helpText1[] =                                
"\n"
"Available commands for config during start-up:\n"
"  b<n>      - set r.f. band n = a single numeral: 4 = 433MHz, 8 = 868MHz, 9 = 915MHz (may require hardware change)\n"
"  g<nnn>    - set Network Group  nnn - an integer (OEM default = 210)\n"
"  i<nn>     - set node ID i= an integer (standard node ids are 1..31)\n"
"  r         - restore sketch defaults\n"
"  s         - save config to EEPROM\n"
"  v         - show firmware version\n"
"  w<x>      - turn RFM Wireless data on or off:\n"
"            - x = 0 for OFF, x = 1 for ON, x = 2 for ON with whitening\n"
"  x         - exit and continue\n"
"  ?         - show this text again\n"
"\n"
"Available commands only when running:\n"
"  k<x> <yy.y> <zz.z>\n"
"            - Calibrate an analogue input channel:\n"
"            - x = a single numeral: 0 = voltage calibration, 1 = ct1 calibration, 2 = ct2 calibration, etc\n"
"            - yy.y = a floating point number for the voltage/current calibration constant\n"
"            - zz.z = a floating point number for the phase calibration for this c.t. (z is not needed, or ignored if supplied, when x = 0)\n"
"            -  e.g. k0 256.8\n"
"            -       k1 90.9 2.00\n"
"  a<xx.x>   - xx.x = a floating point number for the assumed voltage if no a.c. is detected\n"
"  l         - list the config values\n"
"  p<xx.x>   - xx.x = a floating point number for the datalogging period\n" 
"  s         - save config to EEPROM\n"
"  ?         - show this text again\n"
;

struct eeprom {byte nodeID, RF_freq, networkGroup; 
      float vCal, i1Cal, i1Lead, i2Cal, i2Lead, i3Cal, i3Lead, i4Cal, i4Lead, period; 
      int rf_whitening; float assumedVrms;
      } data;

extern DeviceAddress *temperatureSensors;

static void load_config(bool verbose)
{
  byte* src = (byte *)&data;
  
  byte flag=0;
  bool dataPresent = false;
  for (byte j=0; j<sizeof(data); j++) {
    // Check each EEPROM memory location for data, 255 = no data present
    // If data present then increment flag
    if ((EEPROM.read(j) != 255)) flag ++;
    // Serial.print(EEPROM.read(j));
    // Serial.print(" ");
    // Serial.println(flag);

    // Check if EEPROM data matches the expected sizeof data, if not ignore config since this could be for emonTx V3
    if (flag == sizeof(data)) dataPresent = true;
  }
 
  if (dataPresent==true)
  {
    for (byte j=0; j<sizeof(data); j++, src++)
          *src = EEPROM.read(j); 

    // check validity of EEPROM config
    byte invalid_config = 0;
    // rfm node id should be 1..30
    if (data.nodeID>=1 && data.nodeID<=32) nodeID = data.nodeID; else {
      invalid_config++;
//      Serial.println(F("nodeID Invalid"));
    }
    // rfm frequency should be either 433, 868 or 915
    if (data.RF_freq==RF12_433MHZ || data.RF_freq==RF12_868MHZ || data.RF_freq==RF12_915MHZ) RF_freq = data.RF_freq; else {
      invalid_config++;
//      Serial.println(F("RF_freq Invalid"));
    }
    // rfm network group should be 1..212
    if (data.networkGroup>=1 && data.networkGroup<=212) networkGroup = data.networkGroup; else {
      invalid_config++;
//      Serial.println(F("networkGroup Invalid"));
    }
    
    // Calibration values should not be 0 but are less critical
    // and so are copied here without validation
    vCal         = data.vCal;
    i1Cal        = data.i1Cal;
    i1Lead       = data.i1Lead;
    i2Cal        = data.i2Cal;
    i2Lead       = data.i2Lead;
    i3Cal        = data.i3Cal;
    i3Lead       = data.i3Lead; 
    i4Cal        = data.i4Cal; 
    i4Lead       = data.i4Lead;
    
    // data period must be greater than 0
    if (data.period>0) period = data.period; else {
      invalid_config++; 
//      Serial.println(F("period Invalid"));
    }
   
    rf_whitening = data.rf_whitening;
    assumedVrms2  = data.assumedVrms;
      
    if (invalid_config) {
        Serial.print(F("ERROR EEPROM config contains ")); Serial.print(invalid_config); Serial.println(F(" invalid values"));
        Serial.println(F("Consider restoring defaults and re-applying config."));
    }
  }   
  
  if (verbose)
  {
    if (dataPresent) {
      Serial.println(F("Loaded EEPROM config"));
    } else { 
      Serial.println(F("No EEPROM config"));
    }
    list_calibration();
  }    
}

static void showString (PGM_P s) {
  for (;;) {
    char c = pgm_read_byte(s++);
    if (c == 0)
      break;
    if (c == '\n')
      Serial.print('\r');
    Serial.print(c);
  }
}

static void list_calibration(void)
{
  
  Serial.println(F("Settings:"));
  Serial.print(F("Group ")); Serial.print(networkGroup);
  Serial.print(F(", Node ")); Serial.print(nodeID & 0x1F);
  Serial.print(F(", Band ")); 
  Serial.print(RF_freq == RF12_433MHZ ? 433 : 
               RF_freq == RF12_868MHZ ? 868 :
               RF_freq == RF12_915MHZ ? 915 : 0);
  Serial.print(F(" MHz\n\n"));
 
  Serial.println(F("Calibration:"));
  Serial.print(F("vCal = ")); Serial.println(vCal, 6);
  Serial.print(F("assumedV = ")); Serial.println(assumedVrms2);
  Serial.print(F("i1Cal = ")); Serial.println(i1Cal, 6);
  Serial.print(F("i1Lead = ")); Serial.println(i1Lead);
  Serial.print(F("i2Cal = ")); Serial.println(i2Cal, 6);
  Serial.print(F("i2Lead = ")); Serial.println(i2Lead);
  Serial.print(F("i3Cal = ")); Serial.println(i3Cal, 6);
  Serial.print(F("i3Lead = ")); Serial.println(i3Lead);
  Serial.print(F("i4Cal = ")); Serial.println(i4Cal, 6);
  Serial.print(F("i4Lead = ")); Serial.println(i4Lead);
  Serial.print(rf_whitening ? (rf_whitening ==1 ? "RF on":"RF whitened"):"RF off"); Serial.print("\n");
}
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
